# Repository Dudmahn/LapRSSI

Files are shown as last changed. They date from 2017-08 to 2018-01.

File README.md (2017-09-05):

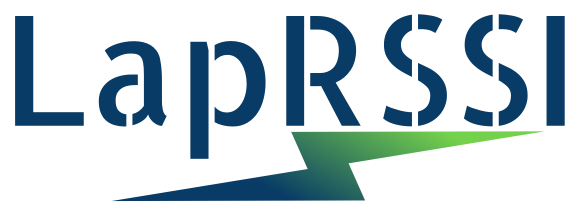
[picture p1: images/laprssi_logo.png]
LapRSSI Logo


# LapRSSI - RF Based Lap Timing Device
LapRSSI is an 8-channel timing device for FPV racing that utilizes the 5.8 GHz analog video signal from the aircraft to perform lap detection. It is intended to be inexpensive, easy to build, and easy to maintain. It functions as a hardware timing device in combination with a PC-based lap timing software such as [LiveTime FPV](https://www.livetimescoring.com/).

LapRSSI consists of a single PJRC Teensy 3.2 microcontroller that interfaces with 8 Boscam RX5808 receivers, and it communicates with the lap timing software via UART serial link. The preferred serial communication device is the [SiK/3DR  Telemetry Radio v2](http://ardupilot.org/copter/docs/common-sik-telemetry-radio.html), which provides a long range 915 MHz wireless link to the timing gate. However, LapRSSI supports other TTL-level UART devices as well, such as the FT232 USB-Serial adapter, or the HC-06 Bluetooth Serial module.

Peak detection is performed on the RSSI signal output on each RX5808 receiver, and the system performs an auto-calibrate sequence at the beginning of each race, in order to determine appropriate signal thresholds for each aircraft.

## License & Recognition
### Recognition
The main inspiration for this project came from the excellent [Delta 5 Race Timer](https://github.com/scottgchin/delta5_race_timer) by Scott Chin. Credit goes to Scott for conceiving the peak detection and auto-calibration algorithms, on which LapRSSI is based.

The [rx5808-pro-diversity](https://github.com/sheaivey/rx5808-pro-diversity) project by Shea Ivey provided insight into the capability to control the RX5808 module via SPI. Credit goes to Shea for the RX5808 frequency tables, which are incorporated into LapRSSI.

Credit goes to Mike Bailey a.k.a. [Hyper-Quad](https://github.com/Hyper-Quad) for the "LapRSSI" name, and also for first conceiving the idea to control 8 RX5808 modules with a single Teensy microcontroller.

Special thanks to  [LiveTime](https://www.livetimescoring.com/) for integrating support for LapRSSI into their lap timing software.

### License
GNU GPLv3

LapRSSI - RF Based Lap Timing Device
Copyright (C) 2017 Steve Lilly

LapRSSI is free software: you can redistribute it and/or modify
it under the terms of the GNU General Public License as published by
the Free Software Foundation, either version 3 of the License, or
(at your option) any later version.

LapRSSI is distributed in the hope that it will be useful,
but WITHOUT ANY WARRANTY; without even the implied warranty of
MERCHANTABILITY or FITNESS FOR A PARTICULAR PURPOSE.  See the
GNU General Public License for more details.

You should have received a copy of the GNU General Public License
along with LapRSSI.  If not, see <http://www.gnu.org/licenses/>.

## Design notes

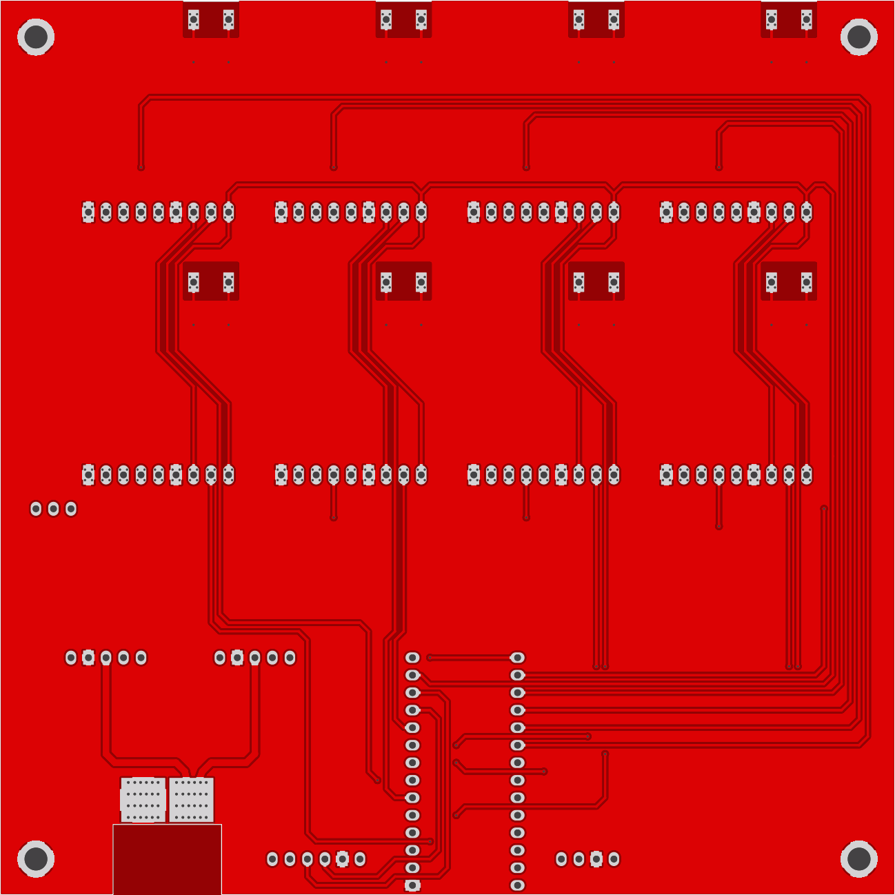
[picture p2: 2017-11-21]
hardware/images/laprssi_pcb_bottom.png

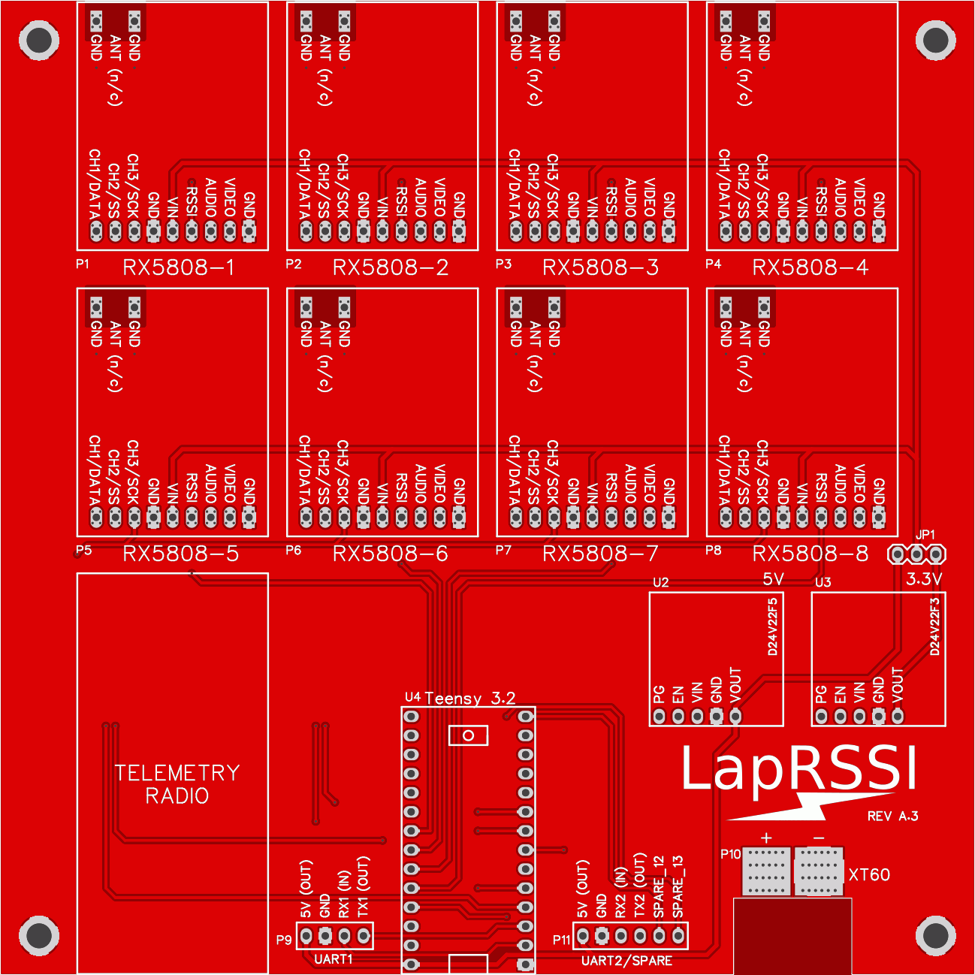
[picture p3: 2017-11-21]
hardware/images/laprssi_pcb_top.png

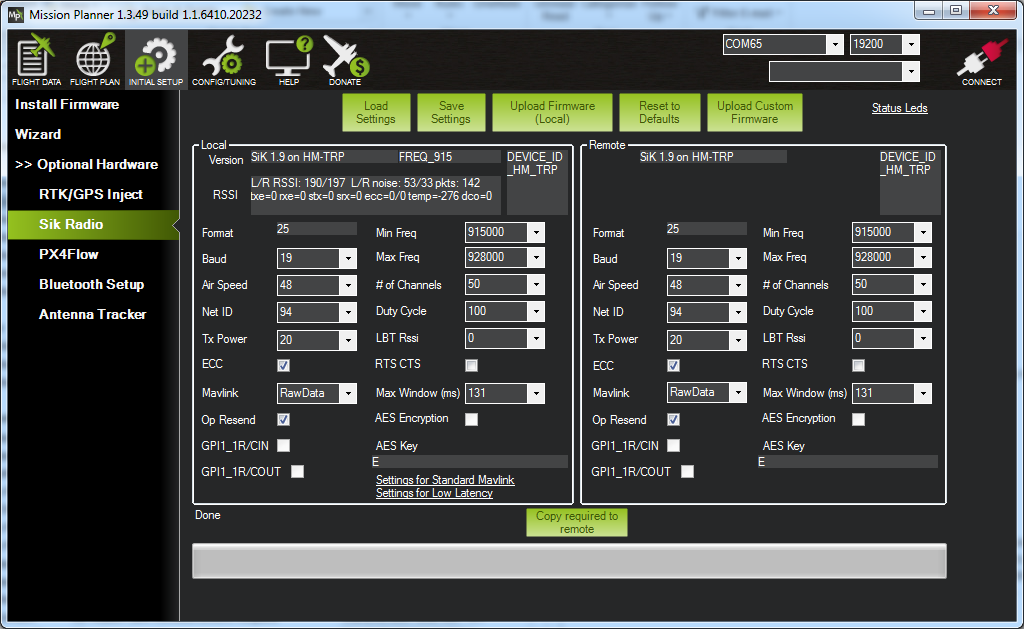
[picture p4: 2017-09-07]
doc/sik_radio_v2_mission_planner_config.png

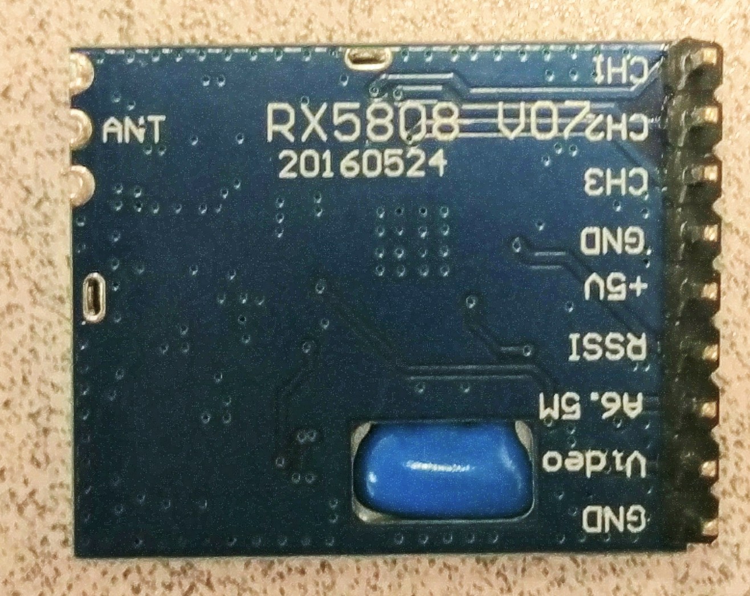
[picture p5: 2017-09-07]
doc/rx5808_module.jpg

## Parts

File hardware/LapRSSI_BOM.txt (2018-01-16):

8x RX5808 Receiver Module w/SPI mod
 - $8.98   https://www.banggood.com/FPV-5_8G-Wireless-Audio-Video-Receiving-Module-RX5808-p-84775.html

1x Teensy 3.2
 - $19.95 https://www.adafruit.com/product/2756

1x Male Header Pins 0.1" break-away, 36-pin, pack of 10
 - $4.95  https://www.adafruit.com/product/392

2x Female Header Pins 0.1", 36-pin, pack of 5
 - $2.95  https://www.adafruit.com/product/598

1x Pololu 3.3V 2.6A Step-Down Voltage Regulator, D24V22F3
 - $8.95  https://www.pololu.com/product/2857

1x Pololu 5V 2.5A Step-Down Voltage Regulator, D24V22F5
 - $8.95  https://www.pololu.com/product/2858

1x Holybro 100mW 915Mhz Telemetry Radio Set
 - $35.00 http://www.getfpv.com/holybro-100mw-fpv-transceiver-telemetry-radio-set-915mhz.html

1x XT60 Male Power Connector
 - $4.49 http://www.getfpv.com/xt60-power-connectors-5-pair.html

1x LapRSSI PCB
 - $10.00 (est.)

4x M3 Stainless Steel Nylock Hex Nuts
 - $4.84 pack of 100 https://www.mcmaster.com/#93625a100/=19rm05i

4x M3x30mm Stainless Steel Socket Head Screw
 - $3.91 pack of 50 https://www.mcmaster.com/#91292a022/=19rm0h9

1x 3D Printed LapRSSI case (top and bottom halves)
 - TBD

Total
=======================================
$178.78 (not including shipping costs)

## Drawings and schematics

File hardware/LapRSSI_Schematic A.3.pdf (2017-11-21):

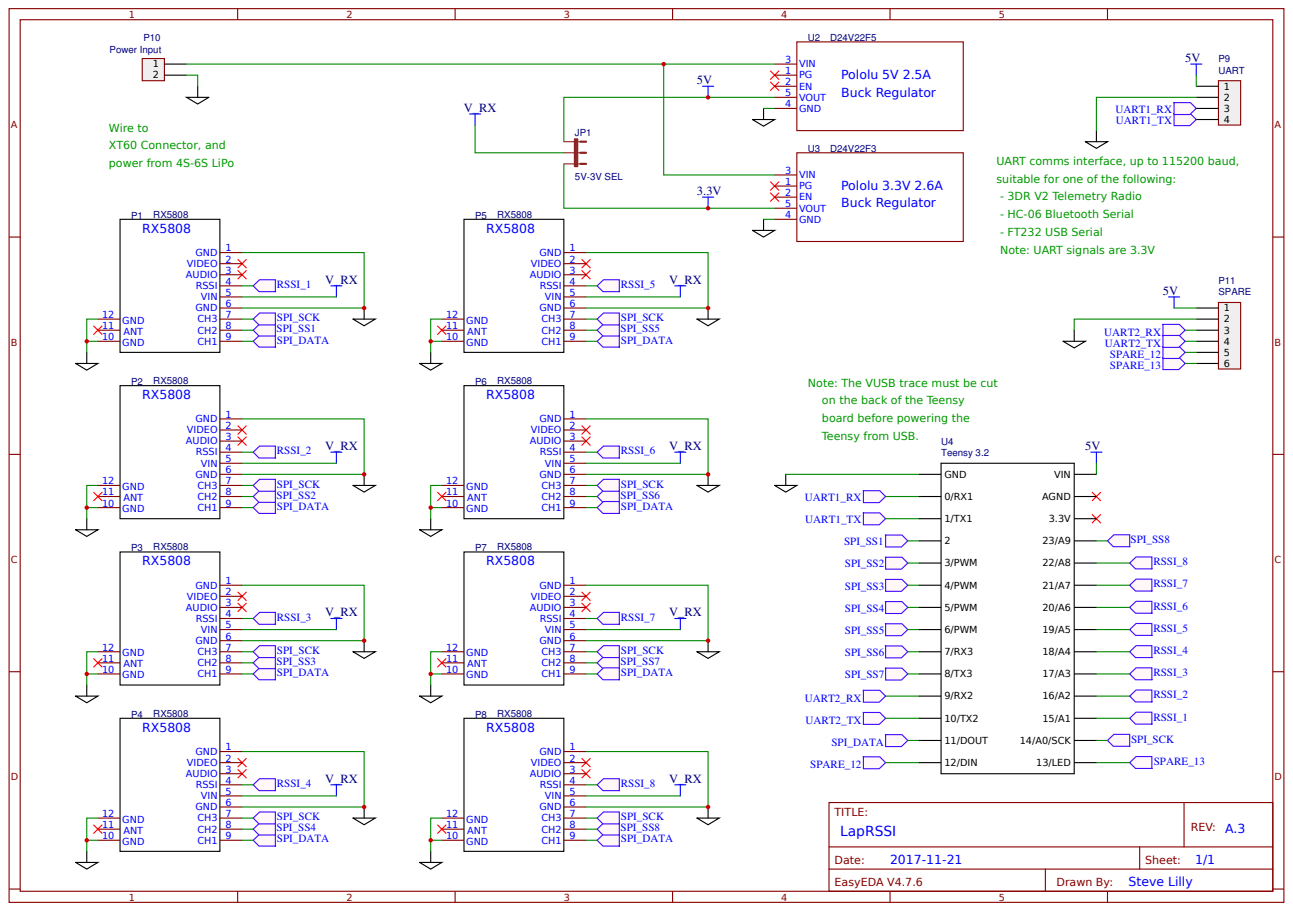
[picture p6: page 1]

UART comms interface, up to 115200 baud,
suitable for one of the following:
- 3DR V2 Telemetry Radio
- HC-06 Bluetooth Serial
- FT232 USB Serial
Note: UART signals are 3.3V

Note: The VUSB trace must be cut
on the back of the Teensy
board before powering the
Teensy from USB.

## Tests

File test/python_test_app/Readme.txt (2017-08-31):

graph_rssi.py is a python script that graphs the data received from the LapRSSI timer.

It can be used to visualize the RSSI data, to aid in tuning the LapRSSI configuration parameters.

Follow these steps to get it running:
===================================================================================
1. Install Python 3.5 from here: https://www.python.org/downloads/release/python-350/
2. Install PyQtGraph from here: http://www.pyqtgraph.org/
3. From a command prompt with Administrator privileges:
    pip install PyQt5
    pip install numpy
    pip install PySerial
4. Install the latest Win32 extensions for your platform (for example pywin32-221.win-amd64-py3.5.exe
   for 64-bit Windows) from here: https://sourceforge.net/projects/pywin32/files/pywin32/
5. From a command prompt with Administrator privileges:
    pip install pyttsx3
   Note: this must be done *after* installing the Win32 extensions as indicated above.
6. Open graph_rssi.py in the Idle Python Gui
7. Edit the comPort variable near the top to match your COM port
8. Hit F5 to run the script

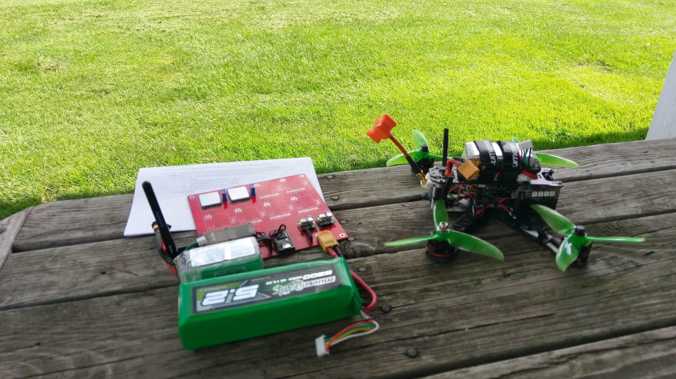
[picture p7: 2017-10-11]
test/test_data/2017-09-29/IMAG0638.jpg

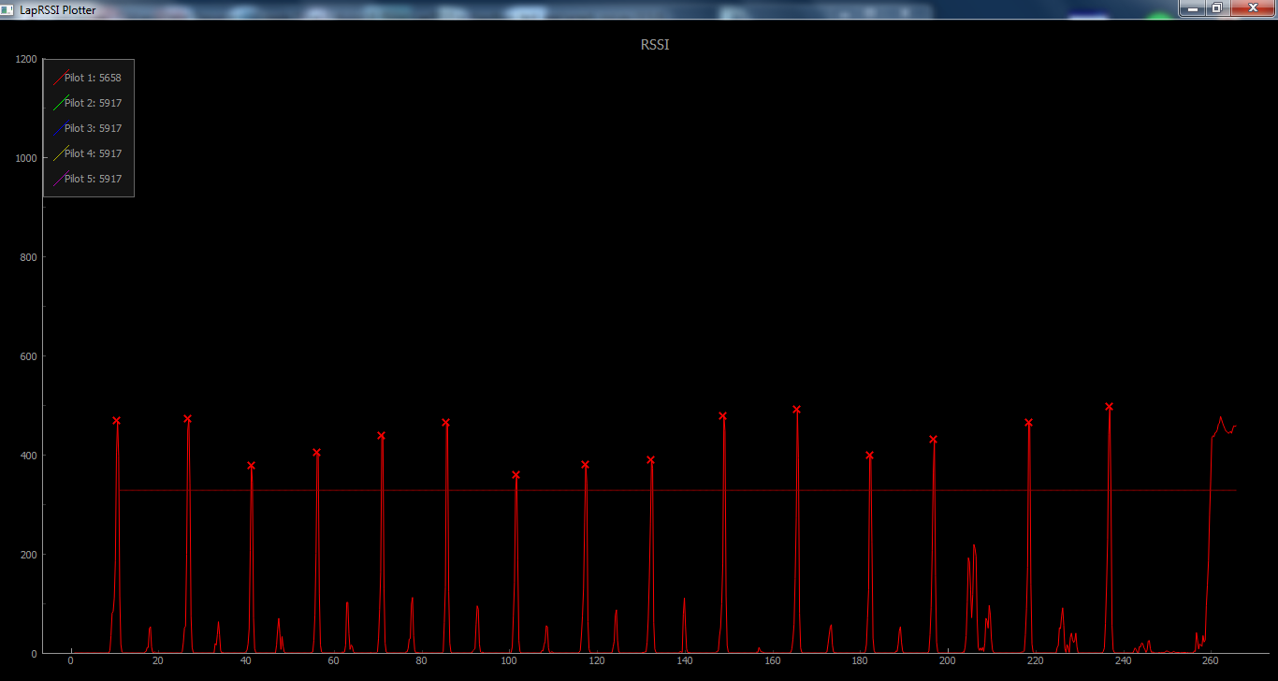
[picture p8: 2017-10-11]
test/test_data/2017-09-29/race_2.png

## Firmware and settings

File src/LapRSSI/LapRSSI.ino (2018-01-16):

//
// LapRSSI - RF Based Lap Timing Device
// Copyright (C) 2017 Steve Lilly
//
// This file is part of LapRSSI.
//
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

#include <errno.h>
#include <EEPROM.h>
#include <limits.h>
#include <ADC.h>
#include <RingBufCPP.h>
#include <SPI.h>  // include the new SPI library

////////////////////////////////////////////////////////////////////////////////
// Defines / Macros
////////////////////////////////////////////////////////////////////////////////
#define FIRMWARE_VERSION                  "1.6"

#define EEPROM_MAGIC_NUMBER               0xEE
#define EEPROM_VERSION                    1

#define MAX_RX_NODES                      8
#define ADC_RESOLUTION                    10
#define ADC_MAX                           ((1 << ADC_RESOLUTION) - 1)
#define ADC_DETECT_THRESH                 200           // RSSI value must be above this level to detect an RX5808 module present
#define ADC_OFFSET                        520
#define ADC_MULTIPLIER                    9
#define ADC_DIVIDER                       4
#define ADC_FILTER_BITS                   5     // 2^5 = 32 samples

#define SERIAL_BAUD_RATE                  19200
#define SERIAL_TX_MSG_MAX_LEN             64            // Max size of a single serial message
#define SERIAL_TX_MSG_QUEUE_LEN           10            // Queue up to 10 serial messages before dropping them

#define HEARTBEAT_REPORT_INTERVAL         1000
#define RSSI_REPORT_INTERVAL_DEFAULT      1000
#define RSSI_REPORT_INTERVAL_MIN          250

// RTC6715 Registers
#define RTC6715_SYNTH_REG_A               0x00
#define RTC6715_SYNTH_REG_B               0x01
#define RTC6715_SYNTH_REG_C               0x02
#define RTC6715_SYNTH_REG_D               0x03
#define RTC6715_VCO_SWITCH_CAP_CTRL_REG   0x04
#define RTC6715_DFC_CTRL_REG              0x05
#define RTC6715_6M_AUDIO_DEMOD_CTRL_REG   0x06
#define RTC6715_65M_AUDIO_DEMOD_CTRL_REG  0x07
#define RTC6715_RECEIVER_CTRL_REG_1       0x08
#define RTC6715_RECEIVER_CTRL_REG_2       0x09
#define RTC6715_POWER_DOWN_CTRL_REG       0x0A
#define RTC6715_STATE_REG                 0x0F

// Definitions for restart CPU macro
#define CPU_RESTART_ADDR (uint32_t *)0xE000ED0C
#define CPU_RESTART_VAL 0x5FA0004
#define CPU_REBOOT() (*CPU_RESTART_ADDR = CPU_RESTART_VAL);


////////////////////////////////////////////////////////////////////////////////
// Type Definitions
////////////////////////////////////////////////////////////////////////////////

// Global configuration parameters
typedef struct {
  int rssiReportIntervalMs;
  int calOffset;
  int calThresh;
  int trigThresh;
  int rssiFilterConstant;
} configParams_t;

// Per receiver node state
typedef struct {
  int enabled;
  int freq;

  bool autoCalibrationMode;
  bool crossing;
  int rssiTrigger;

  int rssiRaw;          // it's actually filtered, but we call it raw
  int rssiPeakRaw;
  uint32_t rssiPeakRawTimestamp;

  float rssiSmoothed;   // longer term "smoothed" RSSI
  int rssiPeakSmoothed;
  
  int rssiPeakSmoothedForRSS; // peak smoothed RSSI value since last RSS message

  // Last lap state
  int lapCount;
  int lapTimestamp;
  int lapTime;
  int lapPeakRssiRaw;
  int lapPeakRssiSmoothed;
} rxNodeState_t;

// Structure used to queue up serial messages for transmission
typedef struct {
  int8_t len;
  char buf[SERIAL_TX_MSG_MAX_LEN];
} serialTxMsg_t;

////////////////////////////////////////////////////////////////////////////////
// Variables
////////////////////////////////////////////////////////////////////////////////

// Serial debug stream
#define DebugSerial   Serial

// GPIO related variables
const int ledPin = 13;

// SPI related variables
const int spiSCKPin = 14;         // SCK on alternate pin
const int spiMOSIPin = 11;
const int spiMISOPin = 12;
const int spiSSPins[MAX_RX_NODES] = { 2, 3, 4, 5, 6, 7, 8, 23 };
const SPISettings spiSettings(4000000, LSBFIRST, SPI_MODE0);

// ADC related variables
ADC *adc;
const int rssiPins[MAX_RX_NODES] = { A1, A2, A3, A4, A5, A6, A7, A8 };

// UART related variables
RingBufCPP<serialTxMsg_t, SERIAL_TX_MSG_QUEUE_LEN> serialTxMsgQueue;

// Global state parameters
int raceNumber = 0;
int heartbeatCounter = 1;
int measurementCount = 0;
elapsedMillis heartbeatReportTimer;
elapsedMillis rssiReportTimer;
elapsedMillis raceTimer;
rxNodeState_t rxNodes[MAX_RX_NODES];
configParams_t cfg = {
  .rssiReportIntervalMs = RSSI_REPORT_INTERVAL_DEFAULT,
  .calOffset = 160,
  .calThresh = 300,
  .trigThresh = 100,
  .rssiFilterConstant = 25    // in thousanths
};

// Define vtx frequencies in mhz and their hex code for setting the rx5808 module
#define FREQ_MIN          5645
#define FREQ_MAX          5945

const int vtxFreqTable[] = {
  5865, 5845, 5825, 5805, 5785, 5765, 5745, 5725, // Band A
  5733, 5752, 5771, 5790, 5809, 5828, 5847, 5866, // Band B
  5705, 5685, 5665, 5645, 5885, 5905, 5925, 5945, // Band E
  5740, 5760, 5780, 5800, 5820, 5840, 5860, 5880, // Band F
  5658, 5695, 5732, 5769, 5806, 5843, 5880, 5917  // Band C / Raceband
};
const uint16_t vtxHexTable[] = {
  0x2A05, 0x299B, 0x2991, 0x2987, 0x291D, 0x2913, 0x2909, 0x289F, // Band A
  0x2903, 0x290C, 0x2916, 0x291F, 0x2989, 0x2992, 0x299C, 0x2A05, // Band B
  0x2895, 0x288B, 0x2881, 0x2817, 0x2A0F, 0x2A19, 0x2A83, 0x2A8D, // Band E
  0x2906, 0x2910, 0x291A, 0x2984, 0x298E, 0x2998, 0x2A02, 0x2A0C, // Band F
  0x281D, 0x288F, 0x2902, 0x2914, 0x2987, 0x2999, 0x2A0C, 0x2A1E  // Band C / Raceband
};
#define NUM_VTX_TABLE_ENTRIES   (sizeof(vtxFreqTable) / sizeof(int))

int installedNodes[] = { 0,    0,    0,    0,    0,    0,    0,    0 };
const int defaultFrequencies[] =  { 5658, 5695, 5732, 5769, 5806, 5843, 5880, 5917 };    // Raceband 8

// This array contains the moving average (sum) for each receiver node. It is accessed
// by the adc0 interrupt, and also by the backgroup loop. In order to prevent reading
// corrupted data, the backgroup loop must disable interrupts when accessing it.
volatile int rssiValMovingAvgSums[MAX_RX_NODES];

////////////////////////////////////////////////////////////////////////////////
// Functions
////////////////////////////////////////////////////////////////////////////////

//
// Setup routine
//
void setup() {
  int i;

  // Debug UART (USB Serial) setup
  DebugSerial.begin(115200);
  delay(1000);
  DebugSerial.println("LapRSSI starting up...");
  
  // Hardware UART setup
  Serial1.begin(SERIAL_BAUD_RATE);
  while (!Serial1) ; // wait until serial port is running
  
  // GPIO pin setup
  pinMode(ledPin, OUTPUT);
  for (i = 0; i < MAX_RX_NODES; i++) {
    pinMode(rssiPins[i], INPUT_PULLDOWN); // setup rssi pin initially with pulldown to detect if modules are installed
  }

  // SPI pins
  for (i = 0; i < MAX_RX_NODES; i++) {
    pinMode(spiSSPins[i], OUTPUT);
    digitalWrite (spiSSPins[i], HIGH);  // set SPI SS pin to idle (high)
  }

  // SPI setup
  SPI.setSCK(spiSCKPin);
  SPI.setMOSI(spiMOSIPin);
  SPI.setMISO(spiMISOPin);
  SPI.begin();

  // ADC Setup
  adc = new ADC();
  adc->setResolution(ADC_RESOLUTION, ADC_0);
  adc->setReference(ADC_REFERENCE::REF_1V2, ADC_0);                 // Use internal 1.2V reference with a 100K pull-down on the RSSI pin
  adc->setConversionSpeed(ADC_CONVERSION_SPEED::HIGH_SPEED, ADC_0);
  adc->setSamplingSpeed(ADC_SAMPLING_SPEED::HIGH_SPEED, ADC_0);
  adc->setAveraging(1, ADC_0);                                      // Disable averaging, because it causes additional delay

  // Delay to let pulldown settle before attempting to detect presence of modules
  delay(10);

  for (i = 0; i < MAX_RX_NODES; i++) {
    // Initialize default frequency
    rxNodes[i].freq = defaultFrequencies[i];
    
    // Determine if this RX5808 module is installed
    if (adc->analogRead(rssiPins[i], ADC_0) >= ADC_DETECT_THRESH) {
      installedNodes[i] = 1;
      rxNodes[i].enabled = 1; // may be overridden below when restoring from EEPROM
    }
    pinMode(rssiPins[i], INPUT);  // remove pulldown
  }

  // Restore configuration, enabled/disable status, and frequencies from EEPROM
  restoreFromEEPROM();

  // Initialize receiver nodes
  for (i = 0; i < MAX_RX_NODES; i++) {
    if (installedNodes[i]) {
      initRxModuleRegisters(i);
      setRxModuleFreq(i, rxNodes[i].freq);
    }
  }
 
  // Start ADC read on the first channel. The ISR routine adc0_isr() will be invoked when the
  // conversion is complete. The ISR will then read the result and trigger a conversion on the next channel.
  adc->enableInterrupts(ADC_0);
  adc->startSingleRead(rssiPins[0], ADC_0);

  // Schedule heartbeat timer to offset with RSSI reports
  heartbeatReportTimer = HEARTBEAT_REPORT_INTERVAL;

  // Reset all receiver nodes
  resetAllRxNodes();

  // Reset race timer
  raceTimer = 0;
}

//
// Main loop
//
void loop() {
  int i;
  int sums[MAX_RX_NODES];
  static uint32_t raceTimerLast = 0;

  //
  // RSSI peak detection algorithm, performed once at the top of every millisecond
  //
  if (raceTimerLast != raceTimer) {
    raceTimerLast = raceTimer;

    //digitalWrite(ledPin, HIGH);

    // Copy RSSI sums to a local array so that we can work with the data without the ADC ISR overwriting it
    cli();    // disable interrupts
    for (i = 0; i < MAX_RX_NODES; i++) {
      sums[i] = rssiValMovingAvgSums[i];
    }
    sei();    // enable interrupts

    for (i = 0; i < MAX_RX_NODES; i++) {
      // Divide the moving average RSSI sum (with rounding) to be the moving average
      rxNodes[i].rssiRaw = (sums[i] + (sums[i] >> (ADC_FILTER_BITS - 1))) >> ADC_FILTER_BITS;
      rxNodes[i].rssiSmoothed = (rxNodes[i].rssiRaw * (cfg.rssiFilterConstant / 1000.0)) + (rxNodes[i].rssiSmoothed * (1.0 - (cfg.rssiFilterConstant / 1000.0)));

      // Update peak smoothed RSSI value for the RSS message
      rxNodes[i].rssiPeakSmoothedForRSS = max(rxNodes[i].rssiPeakSmoothedForRSS, rxNodes[i].rssiSmoothed);

      if (rxNodes[i].enabled) {
        if (rxNodes[i].rssiTrigger > 0) {
          if ((! rxNodes[i].crossing) && (rxNodes[i].rssiSmoothed > rxNodes[i].rssiTrigger)) {
            rxNodes[i].crossing = true;
            //Serial1.print("%DBG\trxNode ");
            //Serial1.print(i);
            //Serial1.print(" crossing ----------------");
            //Serial1.println();
          }

          // Find the peak rssi and the time it occured during a crossing event
          if (rxNodes[i].rssiRaw > rxNodes[i].rssiPeakRaw) {
            rxNodes[i].rssiPeakRaw = rxNodes[i].rssiRaw;
            rxNodes[i].rssiPeakRawTimestamp = raceTimer;
          }

          if (rxNodes[i].crossing) {
            int trigThresh = cfg.trigThresh;

            if (rxNodes[i].autoCalibrationMode) {
              rxNodes[i].rssiTrigger = max(rxNodes[i].rssiTrigger, rxNodes[i].rssiSmoothed - cfg.calOffset);
              // when calibrating, use a larger threshold
              trigThresh = cfg.calThresh;
            }

            rxNodes[i].rssiPeakSmoothed = max(rxNodes[i].rssiPeakSmoothed, rxNodes[i].rssiSmoothed);

            // Make sure the threshold does not put the trigger below 0 RSSI
            // See if we have left the gate
            if ((rxNodes[i].rssiTrigger > trigThresh) &&
              (rxNodes[i].rssiSmoothed < (rxNodes[i].rssiTrigger - trigThresh))) {

              // Crossing complete
              rxNodes[i].lapPeakRssiSmoothed = rxNodes[i].rssiPeakSmoothed;
              rxNodes[i].lapPeakRssiRaw = rxNodes[i].rssiPeakRaw;
              rxNodes[i].lapTime = rxNodes[i].rssiPeakRawTimestamp - rxNodes[i].lapTimestamp;
              rxNodes[i].lapTimestamp = rxNodes[i].rssiPeakRawTimestamp;

              rxNodes[i].crossing = false;
              rxNodes[i].autoCalibrationMode = false;
              rxNodes[i].rssiPeakRaw = 0;
              rxNodes[i].rssiPeakSmoothed = 0;

              // Send LAP message
              sendMsgLAP(i);

              // Update lap count (do this after the LAP report, so the hole shot is reported at lap 0)
              rxNodes[i].lapCount++;
            }
          }
        }
      }
    }

    //digitalWrite(ledPin, LOW);
  }

  // Process incoming comms messages
  rxMessageStateMachine();

  // Periodic Heartbeat report
  if (heartbeatReportTimer >= HEARTBEAT_REPORT_INTERVAL) {
    heartbeatReportTimer = 0;
    sendMsgHRT();
    heartbeatCounter++;
    measurementCount = 0;
  }

  // Periodic RSSI report
  if ((cfg.rssiReportIntervalMs) && (rssiReportTimer >= (uint32_t) cfg.rssiReportIntervalMs)) {
    rssiReportTimer = 0;
    sendMsgRSS(true);
  }

  // Send a queued serial message, if space is available
  handleQueuedSerialTxMsg();
}

// Send a single queued serial message, but only if space is available in the transmit buffer
// This avoids blocking, to prevent delays in the peak detection algorithm.
// Returns true if there are messages still waiting to be send, false if the tx message queue is empty.
bool handleQueuedSerialTxMsg() {
  if (! serialTxMsgQueue.isEmpty()) {
    serialTxMsg_t *pMsg = serialTxMsgQueue.peek(0);
    if (Serial1.availableForWrite() >= pMsg->len) {
      serialTxMsg_t msg;
      serialTxMsgQueue.pull(&msg);
      Serial1.print(msg.buf);
    }
  }

  return ! serialTxMsgQueue.isEmpty();
}

// Restore all settings from EEPROM, including config settings, rx node enabled state, and rx node frequencies
// If the EEPROM contents is determined to be invalid via a simple magic number and version check, then the
// EEPROM is intitialized with default values.
void restoreFromEEPROM() {
  int i, j;
  int idx;
  byte val;
  int freq;
  bool writeDefaults = false;
  
  DebugSerial.println("Restoring settings from EEPROM");

  // Checkl EEPROM magic number
  val = EEPROM.read(0);
  if (val != EEPROM_MAGIC_NUMBER) {
    DebugSerial.println("EEPROM magic number mismatch");
    writeDefaults = true;
  }
  else {
    // Check EEPROM version
    val = EEPROM.read(1);
    if (val != EEPROM_VERSION) {
      DebugSerial.println("EEPROM version mismatch");
      writeDefaults = true;
    }
  }
  
  // Clear the EEPROM settings area, if needed
  if (writeDefaults) {
    DebugSerial.println("Writing defaults to EEPROM");
    
    EEPROM.write(0, EEPROM_MAGIC_NUMBER);
    EEPROM.write(1, EEPROM_VERSION);
    
    saveConfigToEEPROM();
    saveRxEnableToEEPROM();
    saveRxFrequenciesToEEPROM();
  }

  // Restore config settings
  idx = 2;
  for (i = 0; i < sizeof(cfg); i++) {
    val = EEPROM.read(idx++);
    ((byte *)(&cfg))[i] = val;
  }

  // Restore receiver enable/disable
  for (i = 0; i < MAX_RX_NODES; i++) {
    val = EEPROM.read(idx++);
    if ((val != 0) && installedNodes[i]) {
      rxNodes[i].enabled = 1;
    }
    else {
      rxNodes[i].enabled = 0;
    }
  }
  
  // Restore frequencies
  for (i = 0; i < MAX_RX_NODES; i++) {
    freq = EEPROM.read(idx++);
    freq |= EEPROM.read(idx++) << 8;
    for (j = 0; j < NUM_VTX_TABLE_ENTRIES; j++) {
      if (freq == vtxFreqTable[j]) {
        rxNodes[i].freq = freq;
        break;
      }
    }
  }

  DebugSerial.print("rssiReportIntervalMs: ");
  DebugSerial.println(cfg.rssiReportIntervalMs);
  DebugSerial.print("calOffset: ");
  DebugSerial.println(cfg.calOffset);
  DebugSerial.print("calThresh: ");
  DebugSerial.println(cfg.calThresh);
  DebugSerial.print("trigThresh: ");
  DebugSerial.println(cfg.trigThresh);
  DebugSerial.print("rssiFilterConstant: ");
  DebugSerial.println(cfg.rssiFilterConstant);

  for (i = 0; i < MAX_RX_NODES; i++) {
    DebugSerial.print("node ");
    DebugSerial.print(i);
    DebugSerial.print(": enabled=");
    DebugSerial.print(rxNodes[i].enabled);
    DebugSerial.print(", freq=");
    DebugSerial.println(rxNodes[i].freq);
  }
}

void saveConfigToEEPROM() {
  int i;
  int idx;
  
  DebugSerial.println("Saving configuration to EEPROM");
  idx = 2;
  for (i = 0 ; i < sizeof(cfg); i++) {
    EEPROM.write(idx++, ((byte *)(&cfg))[i]);
  }
}

void saveRxEnableToEEPROM() {
  int i;
  int idx;

  DebugSerial.println("Saving rx enables to EEPROM");
  idx = 2 + sizeof(cfg);
  for (i = 0; i < MAX_RX_NODES; i++) {
    EEPROM.write(idx++, rxNodes[i].enabled);
  }
}

void saveRxFrequenciesToEEPROM() {
  int i;
  int idx;

  DebugSerial.println("Saving rx frequencies to EEPROM");
  idx = 2 + sizeof(cfg) + MAX_RX_NODES;
  for (i = 0; i < MAX_RX_NODES; i++) {
    EEPROM.write(idx++, rxNodes[i].freq & 0xff);
    EEPROM.write(idx++, (rxNodes[i].freq >> 8) & 0xff);
  }
}

// State machine to handle incoming messages
void rxMessageStateMachine() {
  const int RX_MSG_BUF_SIZE = 64;
  enum rxState_e { RX_STATE_IDLE, RX_STATE_RECEIVING, RX_STATE_WAIT_NEWLINE, RX_STATE_ERROR };
  static rxState_e rxState = RX_STATE_IDLE;
  static int rxMsgLen = 0;
  static char rxMsgBuf[RX_MSG_BUF_SIZE];
  char ch;
  bool done = false;

  while ((! done) && Serial1.available()) {
    ch = Serial1.read();

    if ((ch == '#') || (ch == '?')) {
      // Begin new message
      rxMsgLen = 0;
      rxMsgBuf[rxMsgLen++] = ch;
      rxState = RX_STATE_RECEIVING;
    }
    else {
      if (rxState == RX_STATE_RECEIVING) {
        if (rxMsgLen < RX_MSG_BUF_SIZE) {
          if (ch == '\r' && (rxMsgLen >= 4)) {
            rxMsgBuf[rxMsgLen] = 0;  // NULL terminate the message
            rxState = RX_STATE_WAIT_NEWLINE;
          }
          else {
            rxMsgBuf[rxMsgLen++] = ch;
          }
        }
        else {
          rxState = RX_STATE_ERROR;
        }
      }
      else if (rxState == RX_STATE_WAIT_NEWLINE) {
        if (ch == '\n') {

          // We got one, now let's see what it contains!
          processRxMessage(rxMsgBuf, rxMsgLen);

          rxState = RX_STATE_IDLE;
          done = true;  // only process 1 message then we're done
        }
        else {
          rxState = RX_STATE_ERROR;
        }
      }
      else if (rxState == RX_STATE_ERROR) {
        // Nothing to do here
      }
    }
  }
}

void processRxMessage(char *msg, int len) {
  int i;

  if (msg[0] == '?' && (len == 4)) {
    // Process queries
    if (! strncmp(&msg[1], "VER", 3)) {
      ////////////////////////////////////////////////////////////////////// ?VER
      sendMsgVER();
    }
    else if (! strncmp(&msg[1], "FRA", 3)) {
      ////////////////////////////////////////////////////////////////////// ?FRA
      sendMsgFRA();
    }
    else if (! strncmp(&msg[1], "REN", 3)) {
      ////////////////////////////////////////////////////////////////////// ?REN
      sendMsgREN();
    }
    else if (! strncmp(&msg[1], "CFG", 3)) {
      ////////////////////////////////////////////////////////////////////// ?CFG
      sendMsgCFG();
    }
    else if (! strncmp(&msg[1], "RSS", 3)) {
      ////////////////////////////////////////////////////////////////////// ?RSS
      sendMsgRSS(false);
    }
  }
  else if(msg[0] == '#' && (len >= 4)) {
    #define MAX_FIELDS    16
    int numFields;
    const char *fields[MAX_FIELDS];

    // Split the message into fields
    numFields = splitFields(&msg[5], fields, MAX_FIELDS);

    //for (i = 0; i < numFields; i++) {
    //  Serial1.print("field ");
    //  Serial1.print(i);
    //  Serial1.print(":");
    //  Serial1.println(fields[i]);
    //}

    // Process commands
    if (! strncmp(&msg[1], "FRA", 3)) {
      ////////////////////////////////////////////////////////////////////// #FRA
      if (numFields == MAX_RX_NODES) {
        int freq;
        for (i = 0; i < MAX_RX_NODES; i++) {
          if (installedNodes[i]) {
            if (convertToInt(fields[i], freq, FREQ_MIN, FREQ_MAX, false)) {
              setRxModuleFreq(i, freq);
            }
          }
        }
        saveRxFrequenciesToEEPROM();
        sendMsgFRA();
      }
    }
    else if (! strncmp(&msg[1], "REN", 3)) {
      ////////////////////////////////////////////////////////////////////// #REN
      if (numFields == MAX_RX_NODES) {
        for (i = 0; i < MAX_RX_NODES; i++) {
          if (installedNodes[i]) {
            // Only allow enable on nodes that are installed
            convertToInt(fields[i], rxNodes[i].enabled, 0, 1, true);
          }
        }
        saveRxEnableToEEPROM();
        sendMsgREN();
      }
    }
    else if (! strncmp(&msg[1], "CFG", 3)) {
      ////////////////////////////////////////////////////////////////////// #CFG
      if (numFields == 5) {
        convertToInt(fields[0], cfg.rssiReportIntervalMs, RSSI_REPORT_INTERVAL_MIN, 10000, true);
        convertToInt(fields[1], cfg.calOffset, 0, ADC_MAX, true);
        convertToInt(fields[2], cfg.calThresh, 0, ADC_MAX, true);
        convertToInt(fields[3], cfg.trigThresh, 0, ADC_MAX, true);
        convertToInt(fields[4], cfg.rssiFilterConstant, 0, 1000, true);
        saveConfigToEEPROM();
        sendMsgCFG();
      }
    }
    else if (! strncmp(&msg[1], "RAC", 3)) {
      ////////////////////////////////////////////////////////////////////// #RAC
      if (numFields == 1) {

        resetAllRxNodes();      // reset all receiver nodes
        raceNumber++;           // increment race number
        raceTimer = 0;          // reset race timer
        sendMsgRAC();
      }
    }
    else if (! strncmp(&msg[1], "RBT", 3)) {
      ////////////////////////////////////////////////////////////////////// #RBT
      // Reboot CPU
      sendMsgRBT();
      while (handleQueuedSerialTxMsg());  // make sure all pending message have been transmitted
      DebugSerial.println("Rebooting...");
      delay(100);
      CPU_REBOOT();
    }
    else if (! strncmp(&msg[1], "DFT", 3)) {
      ////////////////////////////////////////////////////////////////////// #DFT
      // Revert to default settings and reboot
      // Write invalid magic number to EEPROM, this will cause defaults to be written upon the next bootup
      EEPROM.write(0, 0);
      sendMsgDFT();
      while (handleQueuedSerialTxMsg());  // make sure all pending message have been transmitted
      DebugSerial.println("Rebooting...");
      delay(100);
      CPU_REBOOT();
    }
  }
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

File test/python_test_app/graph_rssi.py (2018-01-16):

#
# LapRSSI - RF Based Lap Timing Device
# Copyright (C) 2017 Steve Lilly
#
# This file is part of LapRSSI.
#
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

import pyqtgraph as pg
import time
import serial
import pyttsx3
import winsound

# Configuration
comPort = 'COM65'
#comPort = 'COM50'
#comPort = 'COM75'
historySeconds = 150.0
sayTimes = False
doBeep = True

# Initialize TTS engine
tts = pyttsx3.init()

#tts.say('graph r s s i starting up')
#tts.runAndWait()

# Initialize graphing engine
win = pg.GraphicsWindow(title='LapRSSI Plotter')
win.resize(1000,600)
win.setWindowTitle('LapRSSI Plotter')
pg.setConfigOptions(antialias=True)
p1 = win.addPlot(title='RSSI')
p1.enableAutoRange('x', True)
p1.setYRange(0, 1200, padding=0.0)

legend = p1.addLegend(offset=(1,1))

curTime = 0.000

freq1 = 0
freq2 = 0
freq3 = 0
freq4 = 0
freq5 = 0
freq6 = 0
freq7 = 0
freq8 = 0

rssi1 = []
rssi2 = []
rssi3 = []
rssi4 = []
rssi5 = []
rssi6 = []
rssi7 = []
rssi8 = []

lap1 = []
lap2 = []
lap3 = []
lap4 = []
lap5 = []
lap6 = []
lap7 = []
lap8 = []

threshHi1 = 0
threshHi2 = 0
threshHi3 = 0
threshHi4 = 0
threshHi5 = 0
threshHi6 = 0
threshHi7 = 0
threshHi8 = 0

thresh1 = []
thresh2 = []
thresh3 = []
thresh4 = []
thresh5 = []
thresh6 = []
thresh7 = []
thresh8 = []

def addPoint(a, t, p):
    a.append({'x': t, 'y': p})

def trimOldPoints(a):
    global curTime
    #while((len(a) > 0) and (a[0]['x'] < (curTime - historySeconds))):
    #    a.pop(0)

def processSerialMsg(msg):
    global curTime
    global threshHi1, threshHi2, threshHi3, threshHi4, threshHi5, threshHi6, threshHi7, threshHi8
    global freq1, freq2, freq3, freq4, freq5, freq6, freq7, freq8
    #print(msg)
    msg = msg.rstrip('\r\n')
    fields = msg.split('\t')

    if (fields[0] != '%RSS') and (fields[0] != '%HRT'):
        # Print non-repeating messages to the console
        print(msg)

    if fields[0] == '@FRA':
        if len(fields) == 9:
            freq1 = int(fields[1])
            freq2 = int(fields[2])
            freq3 = int(fields[3])
            freq4 = int(fields[4])
            freq5 = int(fields[5])
            freq6 = int(fields[6])
            freq7 = int(fields[7])
            freq8 = int(fields[8])

    elif fields[0] == '%RSS':
        if len(fields) == 11:
            curTime = float(fields[2]);
            if fields[3]:
                addPoint(rssi1, curTime, int(fields[3]))
                if threshHi1 > 0:
                    addPoint(thresh1, curTime, threshHi1)
            if fields[4]:
                addPoint(rssi2, curTime, int(fields[4]))
                if threshHi2 > 0:
                    addPoint(thresh2, curTime, threshHi2)
            if fields[5]:
                addPoint(rssi3, curTime, int(fields[5]))
                if threshHi3 > 0:
                    addPoint(thresh3, curTime, threshHi3)
            if fields[6]:
                addPoint(rssi4, curTime, int(fields[6]))
                if threshHi4 > 0:
                    addPoint(thresh4, curTime, threshHi4)
            if fields[7]:
                addPoint(rssi5, curTime, int(fields[7]))
                if threshHi5 > 0:
                    addPoint(thresh5, curTime, threshHi5)
            if fields[8]:
                addPoint(rssi6, curTime, int(fields[8]))
                if threshHi6 > 0:
                    addPoint(thresh6, curTime, threshHi6)
            if fields[9]:
                addPoint(rssi7, curTime, int(fields[9]))
                if threshHi7 > 0:
                    addPoint(thresh7, curTime, threshHi7)
            if fields[10]:
                addPoint(rssi8, curTime, int(fields[10]))
                if threshHi8 > 0:
                    addPoint(thresh8, curTime, threshHi8)
            updatePlot()


    elif fields[0] == '%LAP':
        if len(fields) == 9:
            curTime = float(fields[2])
            idx = int(fields[3])
            lapCount = int(fields[4])
            lapTime = float(fields[5])
            peakRssi = int(fields[6])
            threshHi = int(fields[7])
            threshLo = int(fields[8])
            if(idx == 0):
                threshHi1 = threshHi
                addPoint(lap1, curTime, peakRssi)
            if(idx == 1):
                threshHi2 = threshHi
                addPoint(lap2, curTime, peakRssi)
            if(idx == 2):
                threshHi3 = threshHi
                addPoint(lap3, curTime, peakRssi)
            if(idx == 3):
                threshHi4 = threshHi
                addPoint(lap4, curTime, peakRssi)
            if(idx == 4):
                threshHi5 = threshHi
                addPoint(lap5, curTime, peakRssi)
            if(idx == 5):
                threshHi6 = threshHi
                addPoint(lap6, curTime, peakRssi)
            if(idx == 6):
                threshHi7 = threshHi
                addPoint(lap7, curTime, peakRssi)
            if(idx == 7):
                threshHi8 = threshHi
                addPoint(lap8, curTime, peakRssi)
            updatePlot()
            
            if doBeep:
                # Play beep
                beepThreadPool.start(beepWorkerThread())

            if sayTimes:
                # Announce lap time
                speechThreadPool.start(speechWorkerThread(idx + 1, lapCount, lapTime))
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

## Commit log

2016-11-29 Create Preliminary Schematic
2016-11-29 Create Schematic
2017-08-31 Send peak smoothed RSSI in the RSS message
    Send peak smoothed RSSI value in the RSS message, in order to avoid
    missing peaks on the graph in the python script.
    [LapRSSI.ino]
2017-08-31 Ignore .tmp files created by the Arduino IDE
2017-09-01 Tweaks during testing on 8-31-17
    Reorder initialization to make sure the race timer is reset before we
    start plotting points.
    Temporarily disable beep and speech prompt, so we can run the script
    along with LiveTime and avoid overlapping sounds.
    [graph_rssi.py]
2017-09-05 Fix @FRA message off-by-one error. Tweaks for testing.
    Fix off-by-one error when processing the @FRA (frequency) response.
    Set all frequencies to 5800 for testing relative RSSI across all
    modules.
    [graph_rssi.py]
2017-09-07 Schematic updates
    Removed rc lowpass filter, since there's plenty of filtering in
    software, and the RSSI signals from the RX5808 tend to fluctuate wildly
    anyway. This hardware filtering was overkill, and would have made the
    build tougher, more components to place, etc.
    Add 1M trimmer pots for each receiver, which will allow tuning to match
    the RSSI levels between the receivers. I added this because I noticed
    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
2017-09-07 Add gerber files and artwork for PCB rev A.0
    [Gerber_drill.GBL, Gerber_drill.GBS, Gerber_drill.GKO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]
2017-09-07 Add BOM with costs and http links
2017-09-07 Add picture of RX5808 module with factory SPI mod
    I received these modules from a vendor on ebay, and they already had the
    SPI mod done. They appear to be version 7 (V07) with a date code of
    20160524. The modules are newer than the ones pictured in the ebay
    listing, which had a date code of 20120322.
    http://www.ebay.com/itm/FPV-5-8G-Wireless-Audio-Video-Receiving-Module-for-Boscam-for-RX5808-/182506586914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
2017-09-07 Add support for queueing serial transmit messages
    Up to 10 outgoing messages are now buffered up. This is required in
    order to prevent blocking the main loop, due to the decrease in UART
    baud rate from 115200 to 19200.
    [LapRSSI.ino]
2017-09-14 Rev A.1 schematic and gerbers
    [Gerber_drill.GBL, Gerber_drill.GBS, Gerber_drill.GKO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]
2017-09-14 Add instructions on how to add required Arduino libraries to sketch
2017-09-19 LapRSSI schematic/pcb rev A.2
    Fix issue where SPI clk and data lines were routed through the RX5808
    n/c pins.
    The board is now 5.7" square.
    RX5808 pads can now accept through-hole or direct solder of module.
    Placed pads for u.fl antenna connectors, in order to facilitate
    experimentation with antennas for a more directional beam.
    The u.fl antenna connector is only intended to be used when the RX5808
    module is direct soldered to the board. Therefore, the antenna pad
    doesn't have a through-hole.
    Move the "spare" header connector to allow better routing of the
    telemetry radio antenna pigtail.
    [Gerber_drill.GBL, Gerber_drill.GBS, Gerber_drill.GKO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]
2017-10-04 Auto-detect installed modules
    Modules are now auto-detected upon initialization. If a module is not
    installed, then its frequency can't be changed, and it can't be enabled
    via the serial protocol.
    The detection method involves enabling an internal pull-down resistor on
    each module's RSSI signal, and sensing the voltage. When a module is
    installed, the signal will remain above a certain threshold because the
    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
2017-10-11 Serial protocol v1.4 modifications
    Add RBT (reboot) command
    Add DFT (reset to defaults) command
    Add rssi_filter_const parameter to the CFG command to allow
    configuration of the RSSI smoothing filter response
2017-10-11 Python test script now handles all 8 receiver nodes
    Add support for 8 receiver nodes
    Avoid configuration of frequencies, node enable/disable, and most
    settings when starting up. Only configure RSSI report interval. Other
    settings must be configured via docklight.
    [graph_rssi.py]
2017-10-11 Docklight support for v1.4 serial protocol
    Add support for RBT and DFT commands.
    Add rssi_filter_const parameter to CFG command.
    Add new buttons for CFG and REN with user prompts.
2017-10-11 Firmware version 1.5: EEPROM persistence and other improvements
    Store settings (config, receiver enable/disable, and frequencies) in
    EEPROM
    Add support for the "reboot" command
    Add support for "reset to defaults" command
    RSSI smoothing filter constant is now configurable via the serial
    protocol, and can be tweaked for a balance between responsiveness and
    latency.
    Send debug prints to the USB serial interface
    Eliminate attempt at configuring RX5808 gain settings (for now at least)
    Fix bug that caused a walk off the end of vtxFreqTable when a frequency
    is not found
    [LapRSSI.ino]
2017-10-11 Update BOM
    Remove trimmer pots
    Add hardware and case
2017-11-21 Hardware revision A.3
    Remove trimmer pots. Compact board. Swivel radio 90 degrees so that the
    antenna is on the same side as the other connectors. Add jumper to
    select either 3.3V or 5V for the RX5808 modules.
    [Gerber_drill.GBL, Gerber_drill.GBS, Gerber_drill.GKO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]
2018-01-16 Update BOM to show RX5808 modules from banggood.
    The previous modules from eBay turned out to be defective.
